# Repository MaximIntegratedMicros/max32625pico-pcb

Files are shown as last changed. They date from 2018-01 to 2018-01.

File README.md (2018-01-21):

# max32625pico-pcb
MAX32625PICO PCB CAD Data

## Files
File Name | Description
--- | ---
max32625pico.brd  | Cadsoft Eagle Board File (7.5.0)
max32625pico.sch  | Cadsoft Eagle Schematic File (7.5.0)
output-gerb274x_4layer.cam  | Cadsoft Eagle CAM Job (7.5.0)
output/max32625pico.gpi  | Photoplotter Info File
output/max32625pico.GTL  | Top (1) copper
output/max32625pico.GTS  | Top soldermask
output/max32625pico.GTO  | Top silk screen
output/max32625pico.GTP  | Top paste
output/max32625pico.G2L  | Inner GND (2) copper
output/max32625pico.G3L  | Inner PWR (15) copper
output/max32625pico.GBL  | Bottom (16) copper
output/max32625pico.GBS  | Bottom soldermask
output/max32625pico.GBO  | Bottom silk screen
output/max32625pico.GFD  | Fab drawing
output/max32625pico.GML  | Mill Layer
output/max32625pico.dri  | Drill Station Info File
output/max32625pico.TXT  | Excellon Drill File
output/max32625pico.mnt  | Component XY Data File
output/max32625pico_sch.pdf  | PDF Schematic
output/max32625pico_fab.PDF  | PDF Fab Drawing

## Bill Of Materials
[Octopart MAX32625PICO BOM](https://octopart.com/bom-tool/UAmHV0aa)

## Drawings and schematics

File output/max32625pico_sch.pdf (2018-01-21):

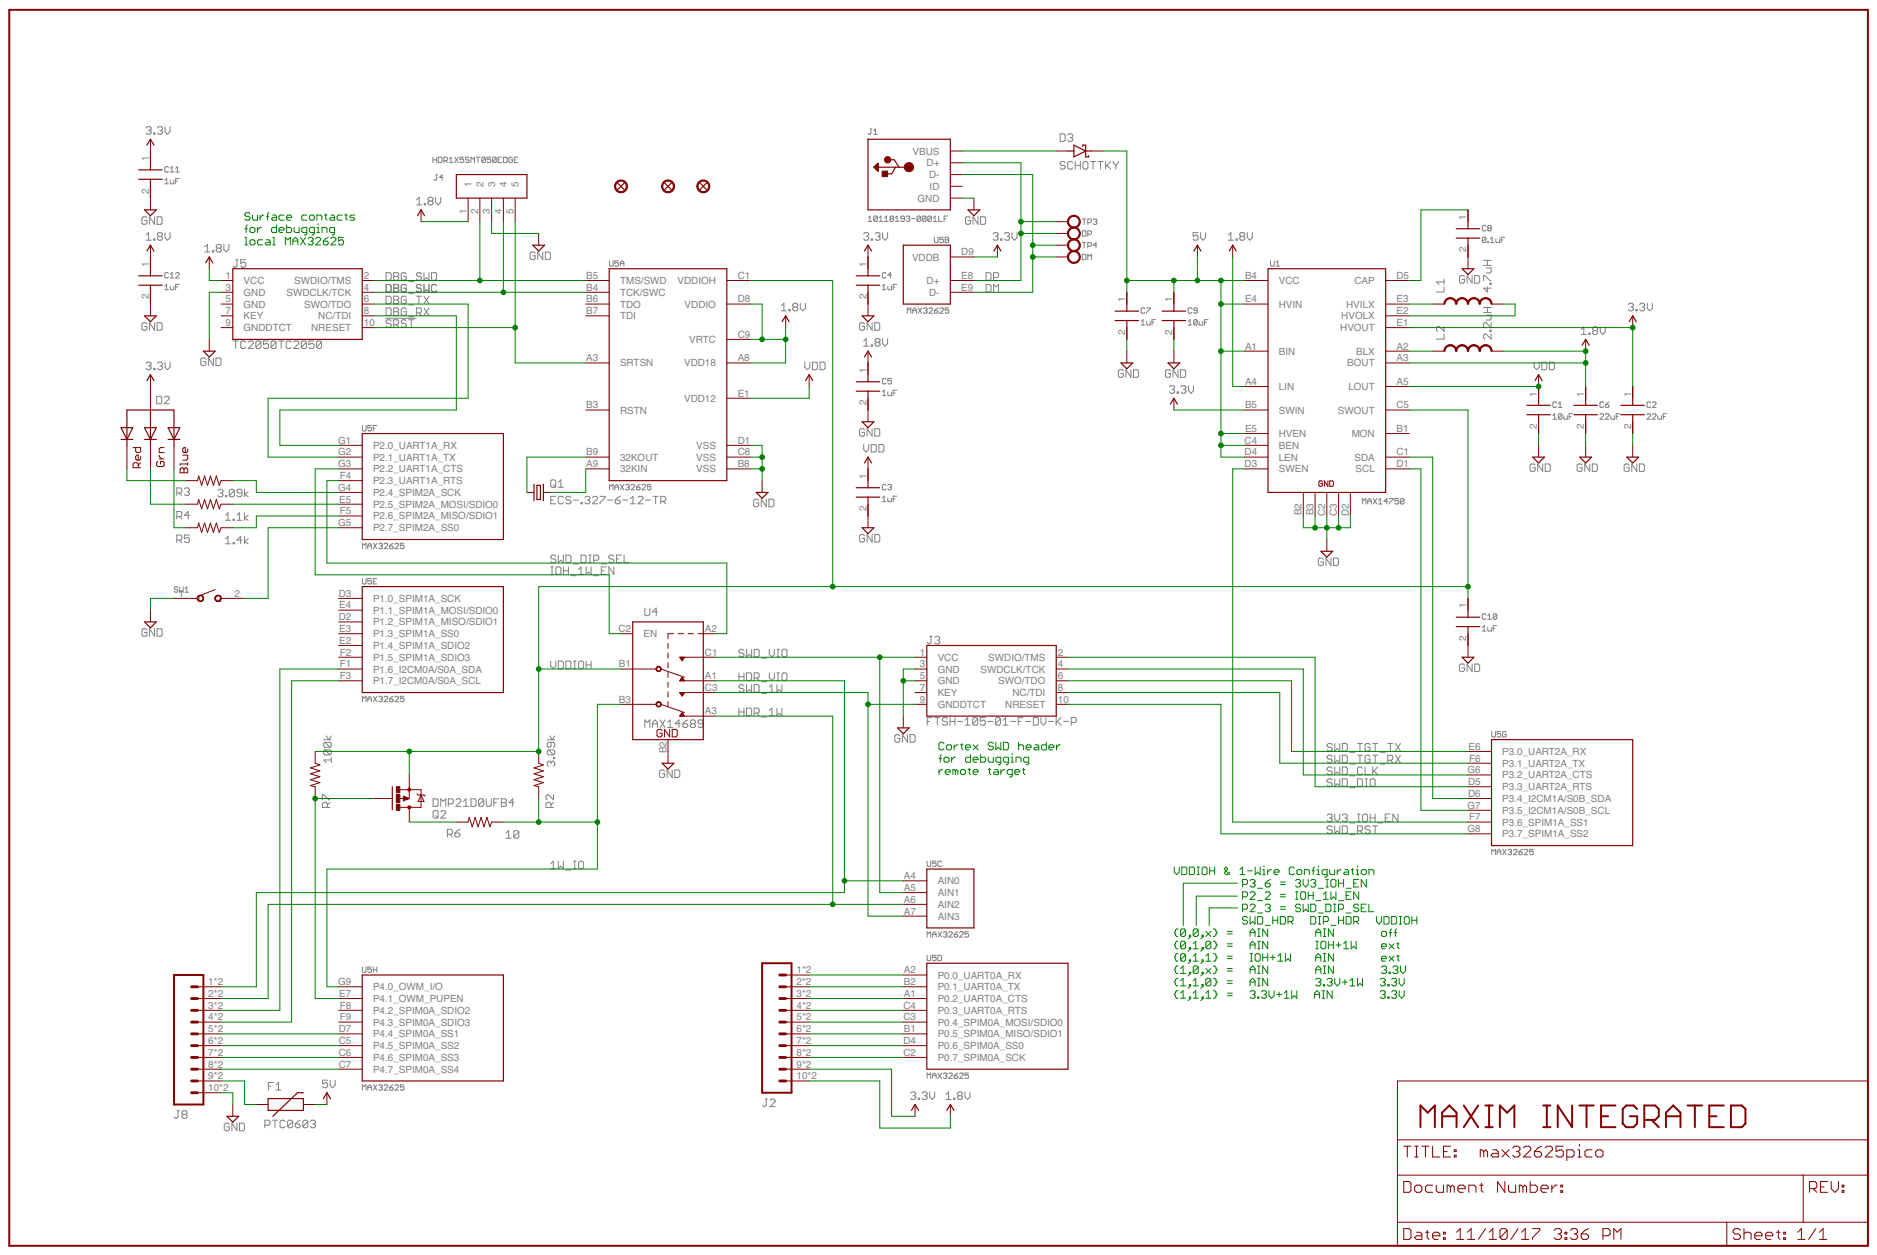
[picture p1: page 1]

1 2 1 2 1 2 1 2 1 2 1*2 2*2 3*2 4*2 5*2 6*2 7*2 8*2 9*2 10*2 1*2 2*2 3*2 4*2 5*2 6*2 7*2 8*2 9*2 10*2 VDDB D9 D+ E8 D- E9 TCK/SWC B4 TMS/SWD B5 TDO B6 TDI B7 VDDIOH C1 VDDIO D8 VSS D1 RSTN B3 SRTSN A3 32KOUT B9 32KIN A9 VSS C8 VSS B8 VDD18 A8 VDD12 E1 VRTC C9 P0.0_UART0A_RX A2 P0.1_UART0A_TX B2 P0.2_UART0A_CTS A1 P0.3_UART0A_RTS C4 P0.4_SPIM0A_MOSI/SDIO0 C3 P0.5_SPIM0A_MISO/SDIO1 B1 P0.6_SPIM0A_SS0 D4 P0.7_SPIM0A_SCK C2 P1.0_SPIM1A_SCK D3 P1.1_SPIM1A_MOSI/SDIO0 E4 P1.2_SPIM1A_MISO/SDIO1 D2 P1.3_SPIM1A_SS0 E3 P1.4_SPIM1A_SDIO2 E2 P1.5_SPIM1A_SDIO3 F2 P1.6_I2CM0A/S0A_SDA F1 P1.7_I2CM0A/S0A_SCL F3 P2.0_UART1A_RX G1 P2.1_UART1A_TX G2 P2.2_UART1A_CTS G3 P2.3_UART1A_RTS F4 P2.4_SPIM2A_SCK G4 P2.5_SPIM2A_MOSI/SDIO0 E5 P2.6_SPIM2A_MISO/SDIO1 F5 P2.7_SPIM2A_SS0 G5 P3.0_UART2A_RX E6 P3.1_UART2A_TX F6 P3.2_UART2A_CTS G6 P3.3_UART2A_RTS D5 P3.4_I2CM1A/S0B_SDA D6 P3.5_I2CM1A/S0B_SCL G7 P3.6_SPIM1A_SS1 F7 P3.7_SPIM1A_SS2 G8 P4.0_OWM_I/O G9 P4.1_OWM_PUPEN E7 P4.2_SPIM0A_SDIO2 F8 P4.3_SPIM0A_SDIO3 F9 P4.4_SPIM0A_SS1 D7 P4.5_SPIM0A_SS2 C5 P4.6_SPIM0A_SS3 C6 P4.7_SPIM0A_SS4 C7 AIN0 A4 AIN1 A5 AIN2 A6 AIN3 A7 VCC 1 GND 3 GND 5 KEY 7 GNDDTCT 9 NRESET 10 NC/TDI 8 SWO/TDO 6 SWDCLK/TCK 4 SWDIO/TMS 2 B1 C1 A1 B3 C3 A3A2 EN C2 B2 HVIN E4 BIN A1 HVEN E5 SWIN B5 B2 CAP D5 HVILX E3 HVOLX E2 HVOUT E1 BLX A2 BOUT A3 SWOUT C5 LOUT A5 BEN C4 LIN A4 VCC B4 SCL D1 SDA C1 LEN D4 MON B1 SWEN D3 B3 C2 C3 D2 1 2 1 2 1 2 1 2 1 2 1 2 1 2 VCC 1 GND 3 GND 5 KEY 7 GNDDTCT 9 NRESET 10 NC/TDI 8 SWO/TDO 6 SWDCLK/TCK 4 SWDIO/TMS 2 1 1 2 2 3 3 4 4 5 5 D+D- GNDID VBUS 1 1 2 2

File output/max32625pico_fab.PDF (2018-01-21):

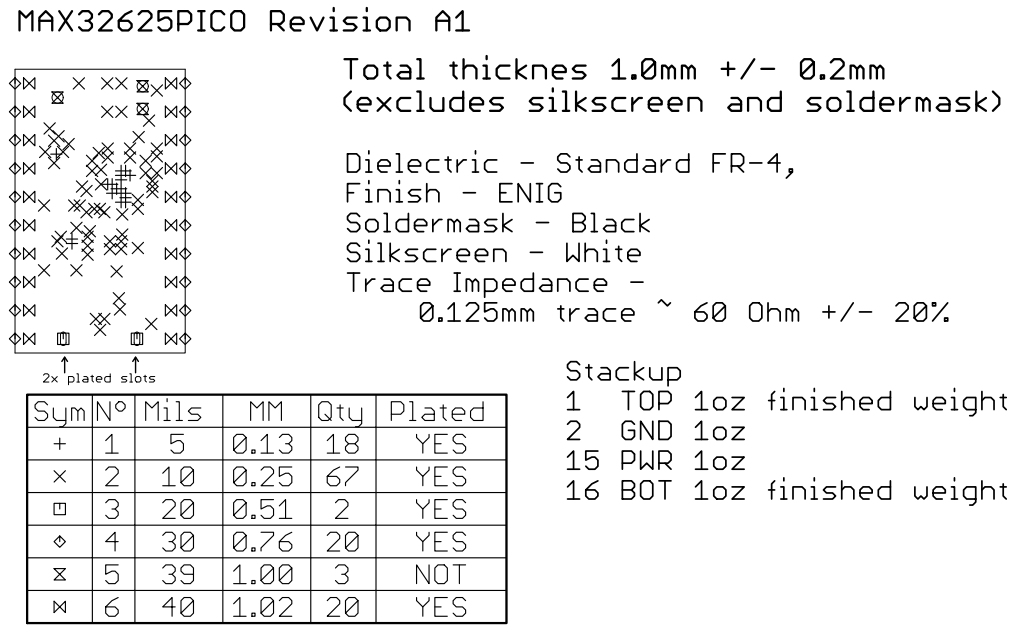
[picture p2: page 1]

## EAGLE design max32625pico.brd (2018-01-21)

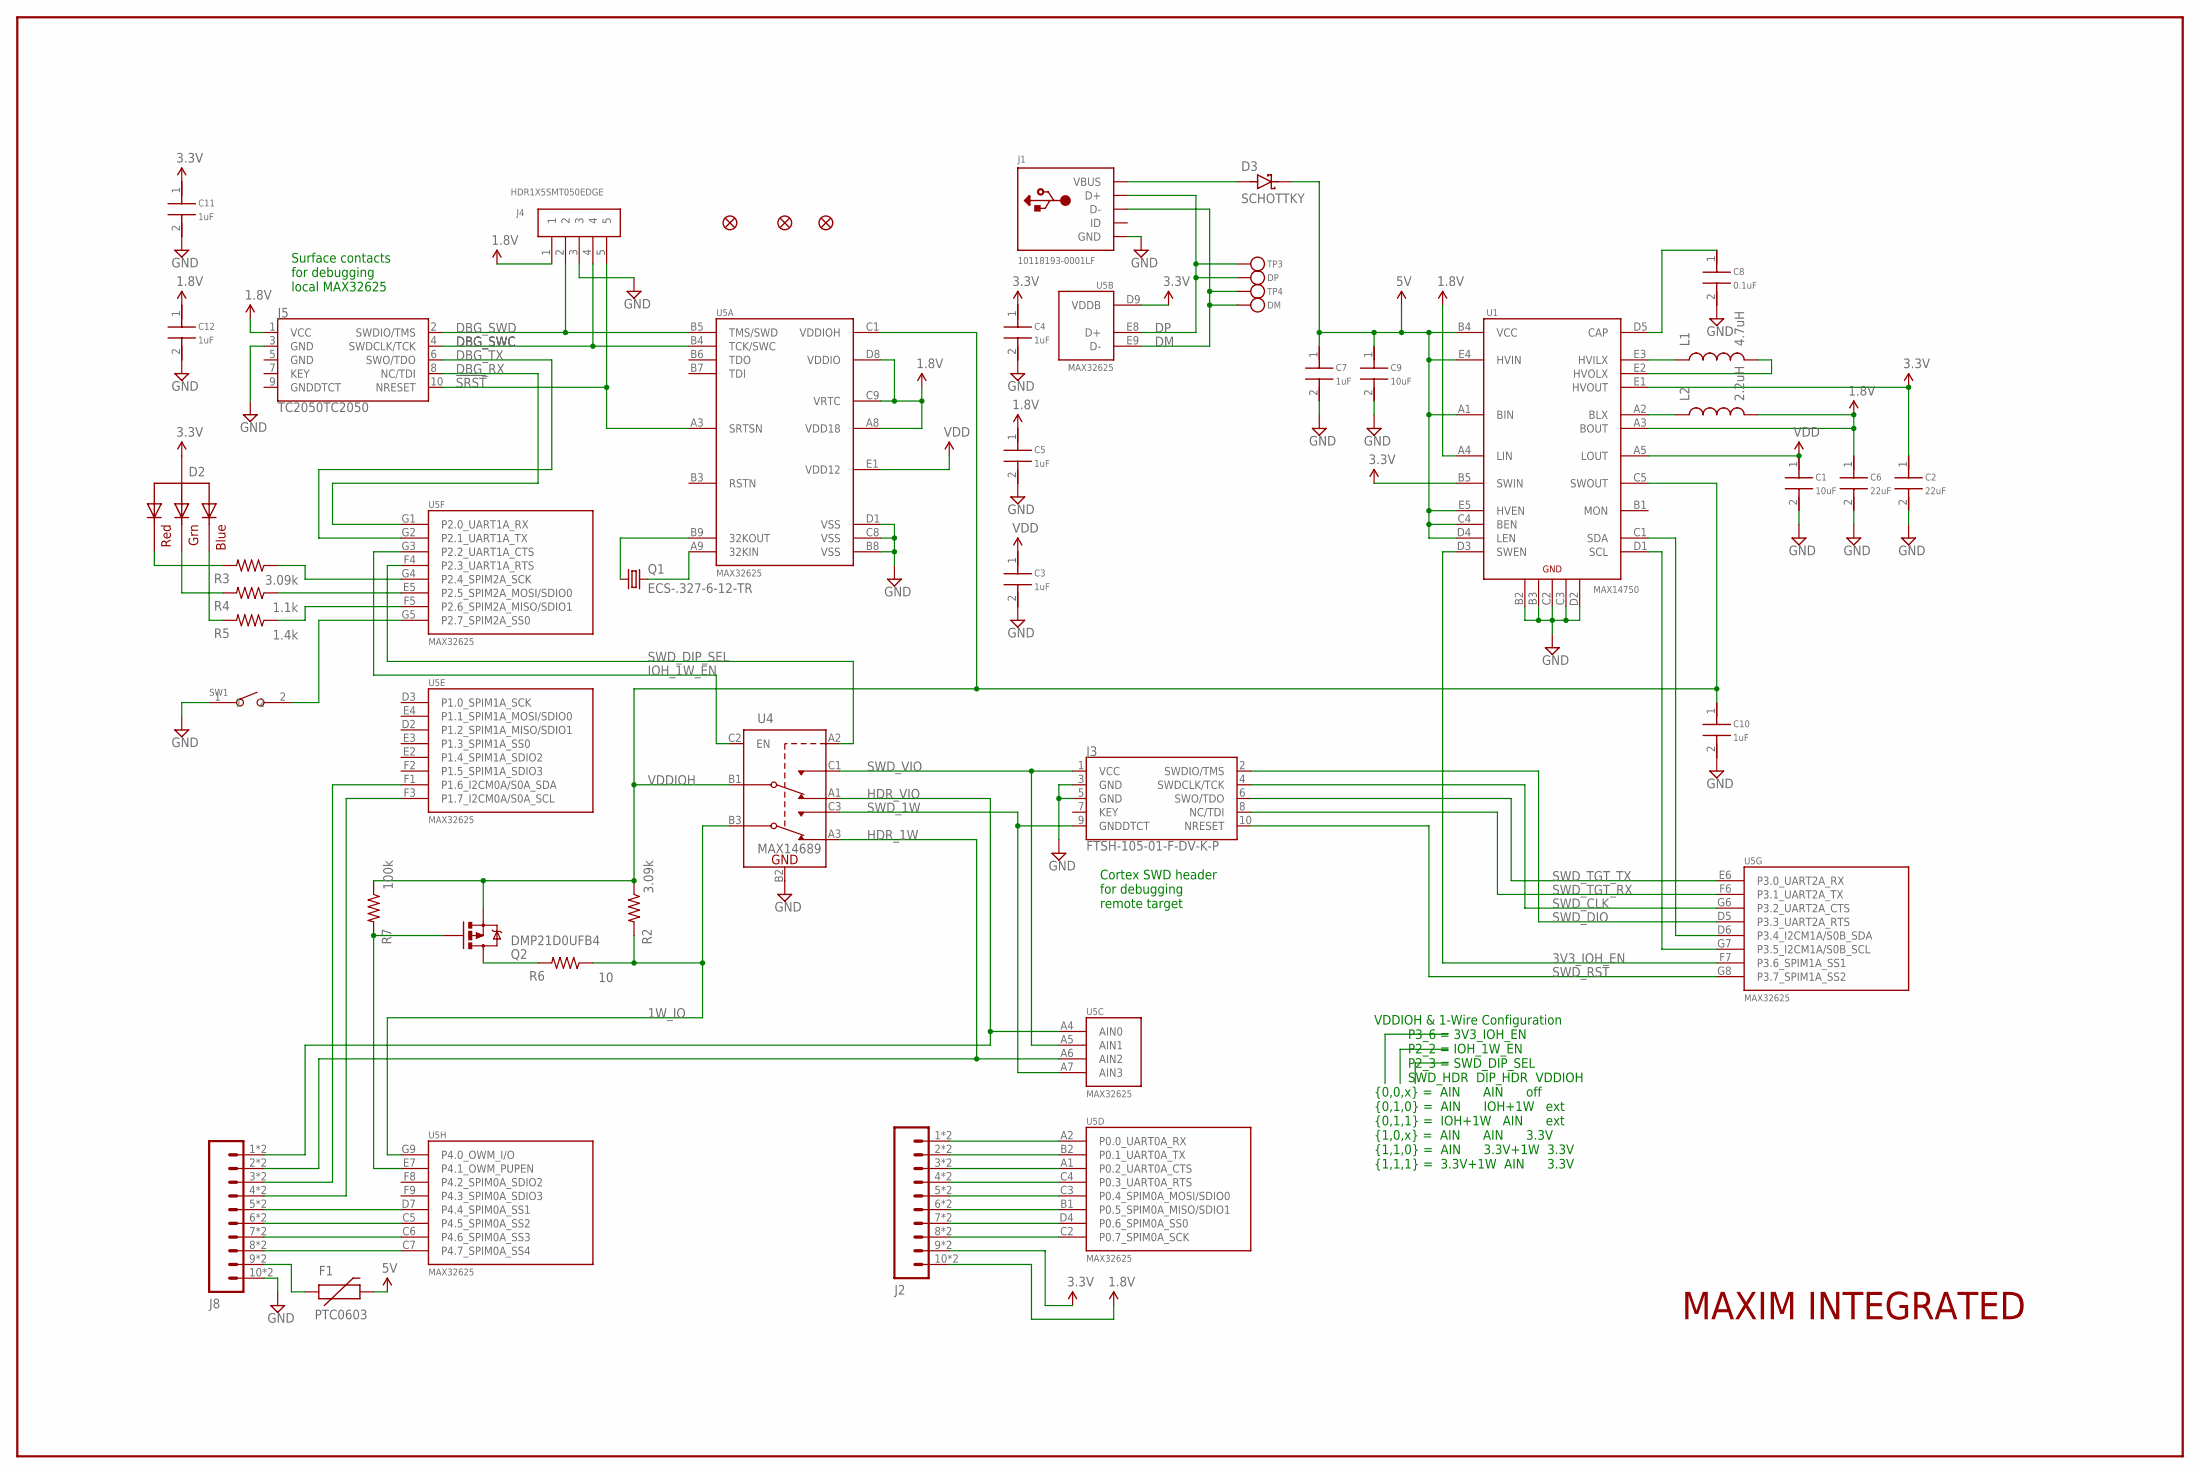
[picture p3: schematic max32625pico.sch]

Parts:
C1, C9: 10uF; 0402
C2, C6: 22uF; 0402
C3, C4, C5, C7, C10, C11, C12: 1uF; 0402
C8: 0.1uF; 0402
D2: RGBLED_CALUMIX-SML-LX0404; LUMIX-SML-LX0404
D3: SCHOTTKY; DCSP1006010-N1
DM: TESTPOINTROUND1.5MM; TESTPOINT_ROUND_1.5MM
DP: TESTPOINTROUND1.5MM; TESTPOINT_ROUND_1.5MM
F1: PTC0603; 0603
FD1, FD2, FD5: FIDUCIALUFIDUCIAL; MICRO-FIDUCIAL
J1: 10118193-0001LF; MICRO-USB5+6P-SMD-0.65-B
J2: M10SMT_L; 1X10_SMT_L
J3: FTSH-105-01-F-DV-K-P; SAMTECH_FTSH-105-01
J4: HDR1X5SMT050EDGE; HDR_SMT_1X5_050_EDGE
J5: TC2050TC2050; TC2050
J8: M10SMT_R; 1X10_SMT_R
L1: 4.7uH; IND2016
L2: 2.2uH; IND2016
Q1: ECS-.327-6-12-TR; FC-12M
Q2: DMP21D0UFB4; SOT-883
R2, R3: 3.09k; 0402
R4: 1.1k; 0402
R5: 1.4k; 0402
R6: 10; 0402
R7: 100k; 0402
SW1: SMD-BUTTON(2P-3.0X2.5X1.2+0.4MM)-B3U-1000P-2P-SMD; SW2-2.6-3.0X2.5X1.2+0.4MM
TP3, TP4: TESTPOINTRECT25X50MIL; TESTPOINT_RECT_25X50MIL
U1: MAX14750; W252M2-1
U4: MAX14689; W91J1-1
U5: MAX32625; W633B3-1
U$1: MAXIM_LOGO; MXM_LOGO_6MM

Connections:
1.8V: C5.1, C6.1, C12.1, J2.10, J2.S10 (10), J4.1, J5.1 (VCC), L2.2, U1.A3 (BOUT), U1.A4 (LIN), U5.A8 (VDD18), U5.C9 (VRTC), U5.D8 (VDDIO)
1W_IO: R2.2, R6.1, U4.B3 (COM2), U5.G9 (P4.0_OWM_I/O)
3.3V: C2.1, C4.1, C11.1, D2.1 (VCC), J2.9, J2.S9 (9), U1.B5 (SWIN), U1.E1 (HVOUT), U5.D9 (VDDB)
3V3_IOH_EN: U1.D3 (SWEN), U5.F7 (P3.6_SPIM1A_SS1)
5V: C7.1, C9.1, D3.1 (C), F1.2, U1.A1 (BIN), U1.B4 (VCC), U1.C4 (BEN), U1.D4 (LEN), U1.E4 (HVIN), U1.E5 (HVEN)
!SRST: J4.5, J5.10 (NRESET), U5.A3 (SRTSN)
DBG_RX: J5.8 (NC/TDI), U5.G1 (P2.0_UART1A_RX)
DBG_SWC: J4.4, J5.4 (SWDCLK/TCK), U5.B4 (TCK/SWC)
DBG_SWD: J4.2, J5.2 (SWDIO/TMS), U5.B5 (TMS/SWD)
DBG_TX: J5.6 (SWO/TDO), U5.G2 (P2.1_UART1A_TX)
DM: DM.P$1, J1.2 (D-), TP4.P$1, U5.E9 (D-)
DP: DP.P$1, J1.3 (D+), TP3.P$1, U5.E8 (D+)
GND: C1.2, C2.2, C3.2, C4.2, C5.2, C6.2, C7.2, C8.2, C9.2, C10.2, C11.2, C12.2, J1.5 (GND), J1.S1 (GND), J1.S2 (GND), J1.S3 (GND), J1.S4 (GND), J1.S5 (GND), J1.S6 (GND), J3.3 (GND), J3.5 (GND), J4.3, J5.3 (GND), J8.10, J8.S10 (10), SW1.1, U1.B2 (GND), U1.B3 (GND), U1.C2 (GND), U1.C3 (GND), U1.D2 (GND), U4.B2 (GND), U5.B8 (VSS), U5.C8 (VSS), U5.D1 (VSS)
HDR_1W: J8.2, J8.S2 (2), U4.A3 (NC2), U5.A6 (AIN2)
HDR_VIO: J8.1, J8.S1 (1), U4.A1 (NC1), U5.A4 (AIN0)
IOH_1W_EN: U4.C2 (EN), U5.G3 (P2.2_UART1A_CTS)
unnamed: J2.1, J2.S1 (1), U5.A2 (P0.0_UART0A_RX)
unnamed: J2.2, J2.S2 (2), U5.B2 (P0.1_UART0A_TX)
unnamed: C8.1, U1.D5 (CAP)
unnamed: J2.3, J2.S3 (3), U5.A1 (P0.2_UART0A_CTS)
unnamed: J2.4, J2.S4 (4), U5.C4 (P0.3_UART0A_RTS)
unnamed: R4.1, U5.E5 (P2.5_SPIM2A_MOSI/SDIO0)
unnamed: R3.1, U5.G4 (P2.4_SPIM2A_SCK)
unnamed: R5.1, U5.F5 (P2.6_SPIM2A_MISO/SDIO1)
unnamed: D2.2 (RED), R3.2
unnamed: D2.4 (GREEN), R4.2
unnamed: D2.3 (BLUE), R5.2
unnamed: D3.2 (A), J1.1 (VBUS)
unnamed: Q1.2, U5.A9 (32KIN)
unnamed: Q1.1, U5.B9 (32KOUT)
unnamed: J2.5, J2.S5 (5), U5.C3 (P0.4_SPIM0A_MOSI/SDIO0)
unnamed: J2.6, J2.S6 (6), U5.B1 (P0.5_SPIM0A_MISO/SDIO1)
unnamed: J2.7, J2.S7 (7), U5.D4 (P0.6_SPIM0A_SS0)
unnamed: J2.8, J2.S8 (8), U5.C2 (P0.7_SPIM0A_SCK)
unnamed: F1.1, J8.9, J8.S9 (9)
unnamed: Q2.3 (D), R6.2
unnamed: J8.8, J8.S8 (8), U5.C7 (P4.7_SPIM0A_SS4)
unnamed: J8.7, J8.S7 (7), U5.C6 (P4.6_SPIM0A_SS3)
unnamed: J8.6, J8.S6 (6), U5.C5 (P4.5_SPIM0A_SS2)
unnamed: J8.5, J8.S5 (5), U5.D7 (P4.4_SPIM0A_SS1)
unnamed: J8.4, J8.S4 (4), U5.F3 (P1.7_I2CM0A/S0A_SCL)
unnamed: J8.3, J8.S3 (3), U5.F1 (P1.6_I2CM0A/S0A_SDA)
unnamed: SW1.2, U5.G5 (P2.7_SPIM2A_SS0)
unnamed: L1.1, U1.E3 (HVILX)
unnamed: L2.1, U1.A2 (BLX)
unnamed: U1.D1 (SCL), U5.G7 (P3.5_I2CM1A/S0B_SCL)
unnamed: L1.2, U1.E2 (HVOLX)
unnamed: U1.C1 (SDA), U5.D6 (P3.4_I2CM1A/S0B_SDA)
unnamed: Q2.1 (G), R7.2, U5.E7 (P4.1_OWM_PUPEN)
SWD_1W: J3.9 (GNDDTCT), U4.C3 (NO2), U5.A7 (AIN3)
SWD_CLK: J3.4 (SWDCLK/TCK), U5.G6 (P3.2_UART2A_CTS)
SWD_DIO: J3.2 (SWDIO/TMS), U5.D5 (P3.3_UART2A_RTS)
SWD_DIP_SEL: U4.A2 (CB), U5.F4 (P2.3_UART1A_RTS)
SWD_RST: J3.10 (NRESET), U5.G8 (P3.7_SPIM1A_SS2)
SWD_TGT_RX: J3.8 (NC/TDI), U5.F6 (P3.1_UART2A_TX)
SWD_TGT_TX: J3.6 (SWO/TDO), U5.E6 (P3.0_UART2A_RX)
SWD_VIO: J3.1 (VCC), U4.C1 (NO1), U5.A5 (AIN1)
VDD: C1.1, C3.1, U1.A5 (LOUT), U5.E1 (VDD12)
VDDIOH: C10.1, Q2.2 (S), R2.1, R7.1, U1.C5 (SWOUT), U4.B1 (COM1), U5.C1 (VDDIOH)

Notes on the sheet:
Surface contacts for debugging local MAX32625
Cortex SWD header for debugging remote target
VDDIOH & 1-Wire Configuration P3_6 = 3V3_IOH_EN P2_2 = IOH_1W_EN P2_3 = SWD_DIP_SEL SWD_HDR DIP_HDR VDDIOH {0,0,x} = AIN AIN off {0,1,0} = AIN IOH+1W ext {0,1,1} = IOH+1W AIN ext {1,0,x} = AIN AIN 3.3V {1,1,0} = AIN 3.3V+1W 3.3V {1,1,1} = 3.3V+1W AIN 3.3V

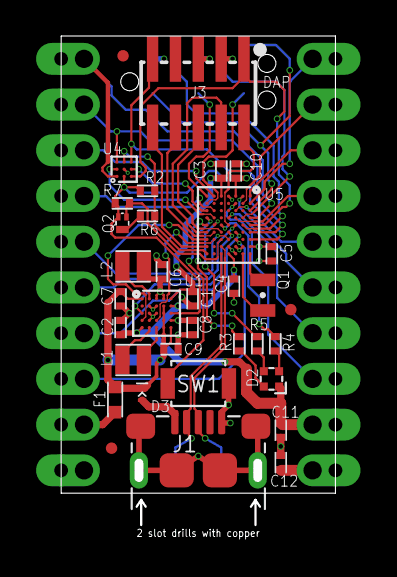
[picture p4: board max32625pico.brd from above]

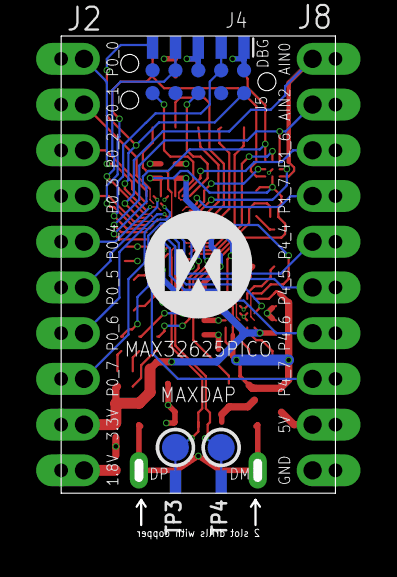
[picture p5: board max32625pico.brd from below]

Board: 4 copper layers, 15.2 x 27.2 mm, 44 parts (9 on the bottom side), 59 nets.

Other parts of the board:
DRILEGEND: DRILEGEND

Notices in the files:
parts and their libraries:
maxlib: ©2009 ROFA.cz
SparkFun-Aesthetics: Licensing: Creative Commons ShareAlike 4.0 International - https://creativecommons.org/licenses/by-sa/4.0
